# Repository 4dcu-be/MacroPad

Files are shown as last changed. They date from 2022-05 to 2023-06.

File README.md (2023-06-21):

# MacroPad
All code and files for setting up a Raspberry Pi Pico powered MacroPad.

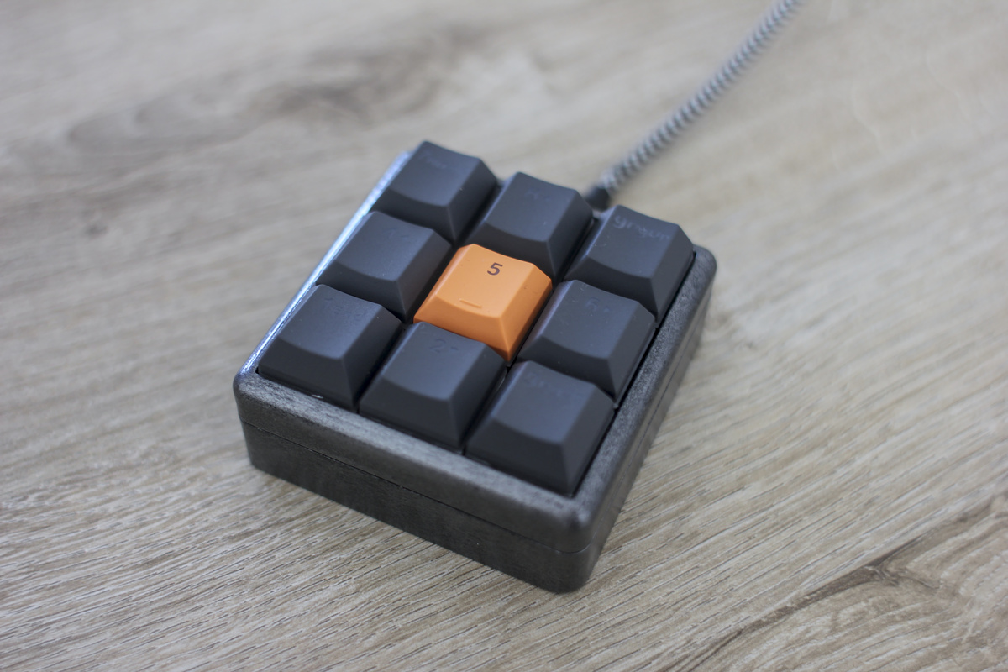
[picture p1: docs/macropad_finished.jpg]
Image of the completed MacroPad


For more instructions/information check out the blog posts about this keyboard:

  * [A Python powered MacroPad/StreamDeck](http://blog.4dcu.be/diy/2021/04/05/Macropad.html)
  * [Tiny MIDI controller with Raspberry Pi Pico](https://blog.4dcu.be/diy/2021/05/20/MIDIpad.html)
  * [Better Raspberry Pi Pico MIDI controller](https://blog.4dcu.be/diy/2021/12/16/MIDIpad_update.html)
  * [Better code for the MacroPad](https://blog.4dcu.be/diy/2022/05/23/Macropad_update.html)

## Building the MacroPad

Here is an overview of all items you'll need to build a MacroPad just like the one above. More detailed instructions can be found the blog [here](http://blog.4dcu.be/diy/2021/04/05/Macropad.html)

*  1x a MacroPad case (3D printed from STL files)
*  1x a Raspberry Pi Pico
*  9x Mechanical keyboard switches (Gateron, Cherry MX, Kailh… should all fit)
*  a set of keycaps (e.g. for numpad keys)
*  9x 1.8 mm 2V LEDs (current 15-20 mA) (optional)
*  9x 82 Ohm resistors (optional)
*  1x a switch opener (optional)
*  4x M3 bolts (14-16mm long)
*  some heat-shrink tubing
*  wire, single core and flexible
*  soldering equipment
*  a third hand tool
*  a hot-glue gun
*  a USB-micro cable

You'll have to wire everything as shown in the schematic below:

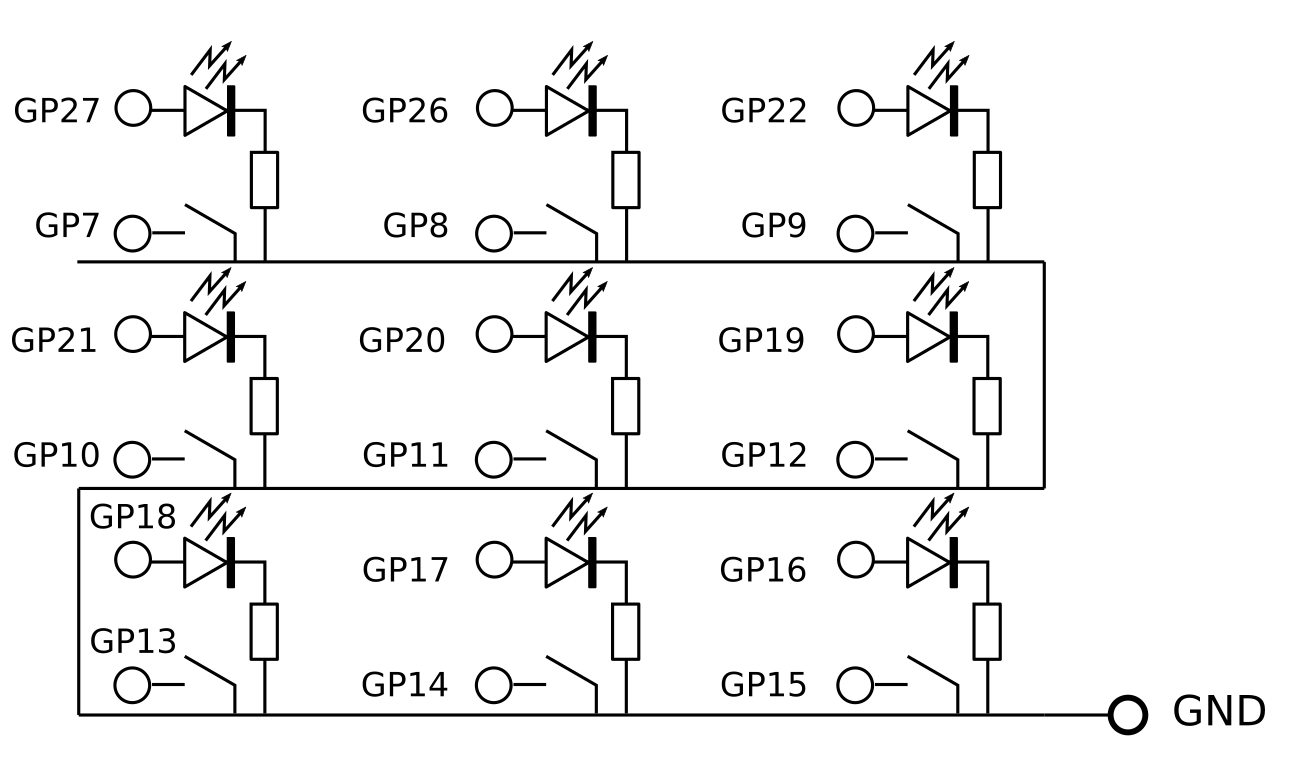
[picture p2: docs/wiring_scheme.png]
Image of how to connect buttons, LEDs to the Pi Pico


Getting the cables the right lenght to fit in the case while still being long enough to hot-glue the pico in place at the end can be tricky. Test fit frequently !

## Preparing the Raspberry Pi Pico

You'll need to install [CircuitPython](https://circuitpython.org/) and the [ADAFruit HID](https://github.com/adafruit/Adafruit_CircuitPython_HID) library. 

## Installing the code

Simply copy the code from the ```./code``` folder to the root folder of the Pi Pico. In case you wish to change the button map, have a look at ```code.py```.

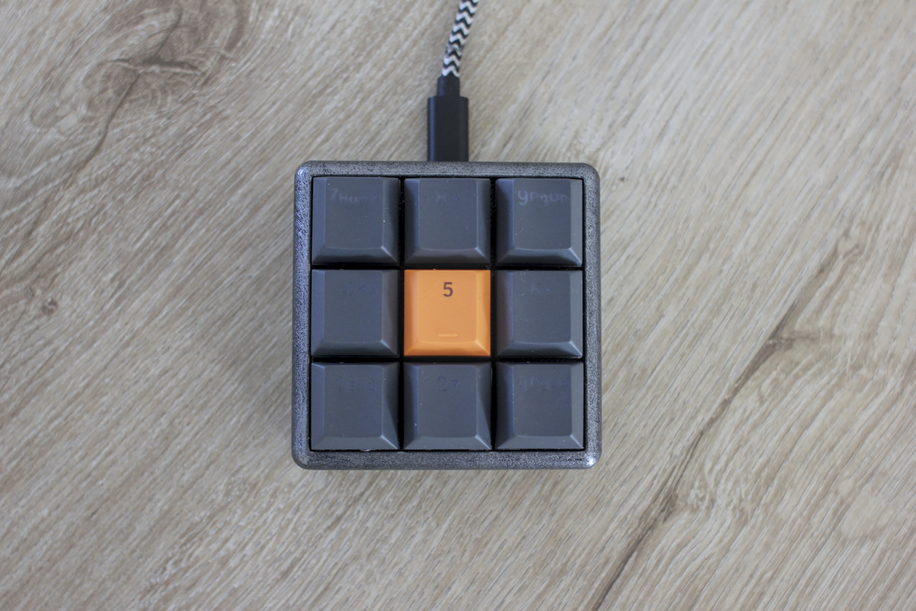
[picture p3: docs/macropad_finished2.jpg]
Image of the completed MacroPad


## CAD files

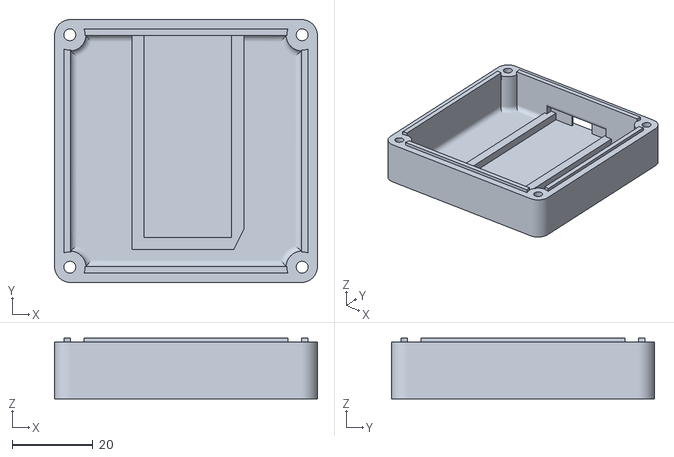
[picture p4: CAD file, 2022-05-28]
stl/pico_macro_pad_bottom_v2.stl
65.2 x 65.1 x 15.0

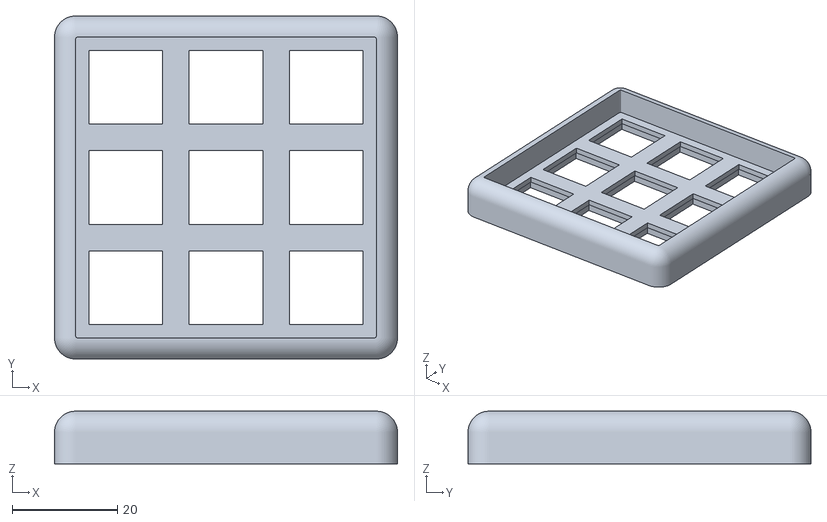
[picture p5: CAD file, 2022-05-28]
stl/pico_macro_pad_top_v2.stl
65.2 x 65.1 x 10.0

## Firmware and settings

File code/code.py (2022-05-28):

import usb_hid
from adafruit_hid.keyboard import Keyboard
from adafruit_hid.keycode import Keycode

from macropad import Macropad

keyboard = Keyboard(usb_hid.devices)

macropad = Macropad()
buttons = macropad.buttons

button_mapping = [
    [Keycode.LEFT_CONTROL, Keycode.WINDOWS, Keycode.LEFT_ARROW],
    [Keycode.WINDOWS, Keycode.TAB],
    [Keycode.LEFT_CONTROL, Keycode.WINDOWS, Keycode.RIGHT_ARROW],
    [Keycode.LEFT_CONTROL, Keycode.F4],
    [Keycode.LEFT_CONTROL, Keycode.F5],
    [Keycode.LEFT_CONTROL, Keycode.F6],
    [Keycode.LEFT_CONTROL, Keycode.F7],
    [Keycode.LEFT_CONTROL, Keycode.F8],
    [Keycode.LEFT_CONTROL, Keycode.F9]]

for btn in buttons:
    @macropad.on_press(btn)
    def press_button(button):
        print(f"pressed {button.number}")
        keyboard.press(*button_mapping[button.number])

    @macropad.on_release(btn)
    def release_button(button):
        print(f"released {button.number}")
        keyboard.release(*button_mapping[button.number])
    
while True:
    macropad.update()

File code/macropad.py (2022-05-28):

import board
import digitalio
import pwmio
import time

# Configuration, which LED pins are used, which buttons, how buttons map to macros
led_pins = [board.GP18,board.GP17,board.GP16,board.GP21,board.GP20,board.GP19, board.GP27, board.GP26,board.GP22]
button_pins = [board.GP13,board.GP14,board.GP15, board.GP10,board.GP11,board.GP12,board.GP7,board.GP8,board.GP9]

class Button(object):
    def __init__(self, button_index, button_pin, led_pin, repeat=True, repeat_time=0.075, first_repeat_time=0.5):
        self.number = button_index
        
        self.button = digitalio.DigitalInOut(button_pin)
        self.button.direction = digitalio.Direction.INPUT
        self.button.pull = digitalio.Pull.UP
        
        self.led = pwmio.PWMOut(led_pin, frequency=1000, duty_cycle=0)
        self.last_pressed = 0
        
        self.triggered = False
        
        self.on_press = None
        self.on_release = None
        
        self.repeat = repeat
        self.repeat_time = repeat_time
        self.first_repeat_time = first_repeat_time
        self.first_repeat = True
        
        self.time_of_last_press = time.monotonic()

    
    @property
    def pressed(self):
        return not self.button.value
    
    def set_duty_cycle(self, value):
        self.led.duty_cycle = value
    
    def fade(self, value=900):
        self.led.duty_cycle = max(self.led.duty_cycle - value, 0)
    
    def update(self):
        self.time_since_last_press = time.monotonic() - self.time_of_last_press
        
        if self.pressed and (not self.triggered or
                             (self.time_since_last_press > self.repeat_time and self.repeat and not self.first_repeat) or
                             (self.time_since_last_press > self.first_repeat_time and self.first_repeat and self.repeat)):
             
             self.time_of_last_press = time.monotonic()
             
             if self.time_since_last_press > self.first_repeat_time and self.first_repeat and self.triggered:
                 self.first_repeat = False
                 
             self.triggered = True
            
             self.set_duty_cycle(65025)
                 
             if self.on_press is not None:
                 self.on_press(self)
                
        elif self.triggered and not self.pressed:
            self.first_repeat = True
            self.triggered = False
            
            if self.on_release is not None:
                self.on_release(self)
                
        self.fade()

class Macropad(object):
    def __init__(self):
        print("Init Macropad")
        
        # Set up buttons
        self.buttons = []
        for ix, (bp, lp) in enumerate(zip(button_pins, led_pins)):
            self.buttons.append(Button(ix, bp, lp))
    
    def on_press(self, button, handler=None):
        if button is None:
            return
        
        def attach_handler(handler):
            button.on_press = handler

        if handler is not None:
            attach_handler(handler)
        else:
            return attach_handler
    
    def on_release(self, button, handler=None):
        if button is None:
            return
        
        def attach_handler(handler):
            button.on_release = handler

        if handler is not None:
            attach_handler(handler)
        else:
            return attach_handler
    
    def update(self):
        for btn in self.buttons:
            btn.update()
            
        time.sleep(0.01)
